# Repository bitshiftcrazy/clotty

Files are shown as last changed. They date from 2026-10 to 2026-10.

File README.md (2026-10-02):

# Clotty

Clotty is a uterus-shaped RP2040 period-tracking companion, sensor board and tiny gaming device.

<p align="center">
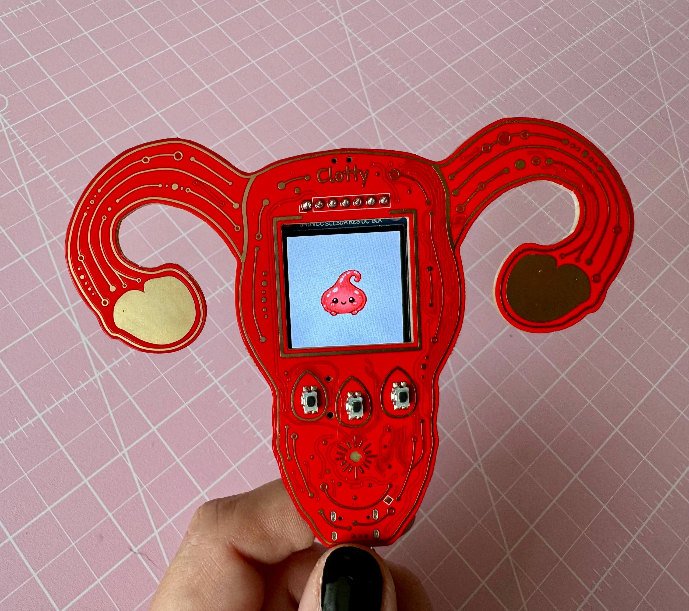
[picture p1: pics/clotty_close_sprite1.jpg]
Clotty showing her little sprite
  
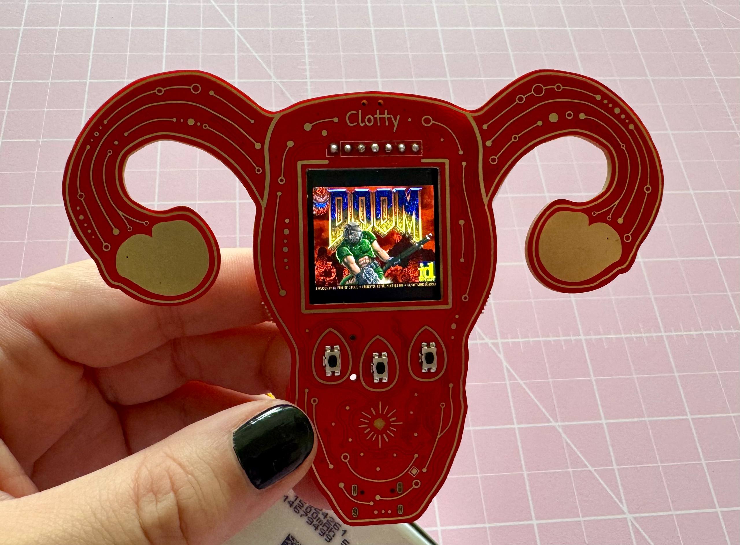
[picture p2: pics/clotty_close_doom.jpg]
Clotty running DOOM
  
</p>

## What is Clotty?

Clotty is a uterus-shaped, custom RP2040-based hybrid between a sensor board and a gaming device.

She originated from the wish to have an offline-only, privacy-focused period tracker that also happens to gamify the unpleasant, recurrent experience of, well, having a period.

Similar to a Tamagotchi, Clotty accompanies the user (currently: me) throughout the cycle. The goal is to keep her (and ideally myself) alive and happy, while her mood, constitution and little quests change according to the current cycle phase. Some of those quests interact with the physical environment through the board's sensors.

Clotty keeps track of cycle lengths and period dates, but she is **not a medical device** beyond that basic tracking functionality.

Naturally, she runs DOOM as well.

## Current Status

> [!WARNING]
> **Work in progress!**
>
> Clotty is currently at the **first working prototype** stage.
>
> Basic board functionality has been tested and confirmed, but there are known hardware issues and plenty of things I still want to improve.
>
> Please keep that in mind before having this revision fabricated.

Current (basic) bring-up status:

- RP2040 boots and can be flashed
- USB enumerates
- display works
- all three physical buttons work
- both capacitive-touch ovaries work
- temperature sensor works
- ambient-light sensor works
- accelerometer works
- Hall sensor works
- RTC works
- RGB LED works
- LiPo charging works
- basic battery-powered operation works
- DOOM runs
- nothing has exploded (yet)

However, testing is still ongoing! 

## Features

Clotty currently or eventually aims to provide:

- completely offline period tracking
- storage of previous cycle lengths and period dates
- basic prediction of likely future period dates
- cycle-phase-dependent moods
- cycle-phase-dependent quests
- cycle-phase-dependent profound wisdom (eg "everyone hates you" during luteal)
- sensor-based interactions with the environment
- small minigames
- animated Clotty sprites
- RGB cycle-phase indication (menacing menstruation maroon, friendly follicular fuchsia, overjoyed ovulation orchid, looming luteal lava...just examples)
- capacitive-touch ovaries for directional interaction
- battery-powered portable operation
- unreasonable amounts of tiny pixel-art accessories
- DOOM, obviously

## Hardware

Main hardware includes:

- **RP2040** microcontroller
- **W25Q128JVSIQ** 128 Mbit / 16 MiB QSPI flash
- **1.3" 240×240 IPS TFT**, driven by an ST7789
- **RV-8263-C7** real-time clock
- RGB LED
- three physical push buttons
- two capacitive-touch ovaries
- USB-C connector
- LiPo charging and power-management circuitry
- currently a 1,500mAh LiPo

<p align="center">
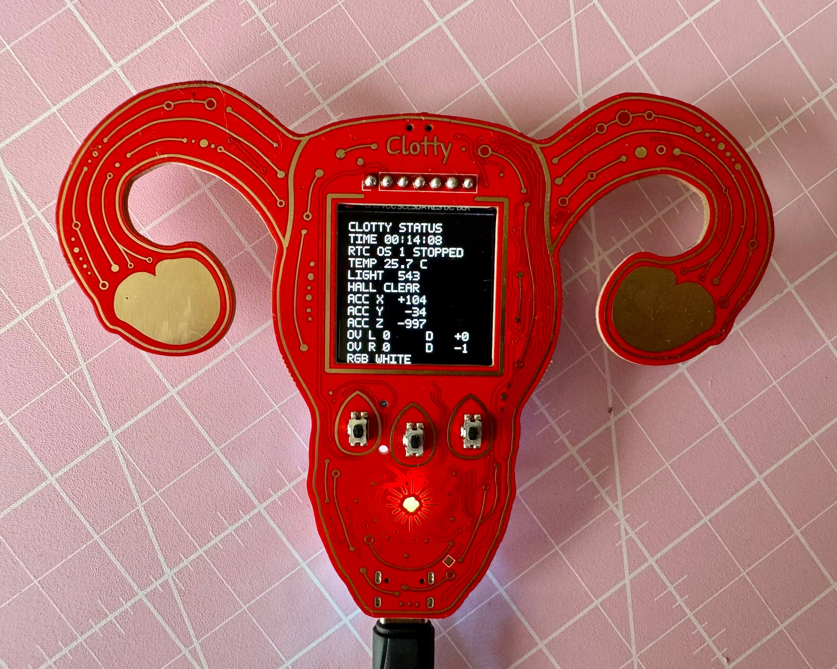
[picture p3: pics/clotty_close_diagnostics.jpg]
Clotty displaying live sensor diagnostics
  
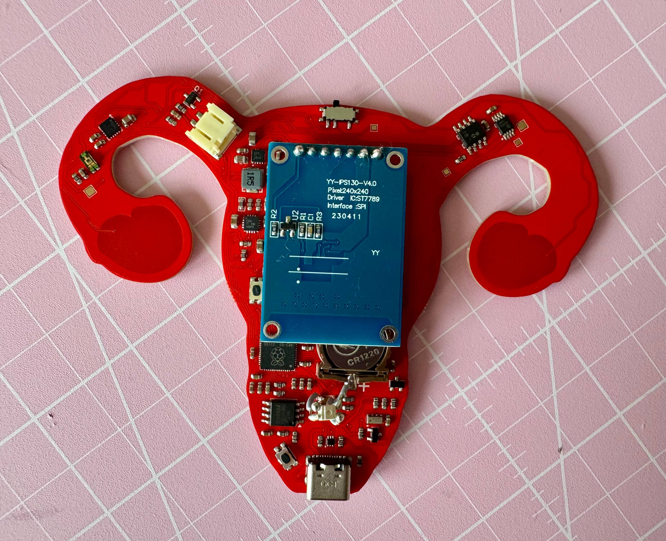
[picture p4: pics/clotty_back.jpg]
Back side of the Clotty PCB
  
</p>

### Sensors

Clotty's sensor selection follows a very scientific design process largely based on "that would be kinda neat".

- **MCP9808-E/MS**: temperature
- **TEMT6000X01**: ambient light
- **LIS3DHTR**: 3-axis accelerometer
- **DRV5032FADBZR**: Hall-effect sensor
- **CAP1203**: capacitive-touch controller for the ovaries

Possible gameplay uses include things like warming Clotty up for a "hot water bottle" quest, putting her somewhere dark for a nap, moving around, or interacting with magnets for no particularly defensible reason.

### Display and Controls

Clotty uses a 240×240 IPS TFT driven by an ST7789.

Controls consist of:

- three physical push buttons
- capacitive-touch ovaries for left and right

The physical buttons are intended mainly for menu navigation and will eventually receive translucent red resin caps shaped like blood drops.

The ovaries are intended for directional or contextual interaction.

Yes, the ovaries also work as controls in DOOM.

### Power

Clotty is designed for portable LiPo-powered operation.

The board includes:

- USB-C input
- LiPo charging
- buck-boost conversion
- power-path / power-selection circuitry
- RTC backup battery

See the schematic for the exact implementation.

## Design

Primarily, the uterus-shape was chosen because it's a period tracking device and subtlety is not exactly my strength.
Periods and reproductive health are still stigmatised too often and Clotty's design is meant to help normalising a biological cycle thanks to which all of us are here in the first place.

But it also turns out that, for reasons nature most likely did not intend, a uterus is surprisingly game-controller-shaped.

The ovaries make convenient touch areas, the centre provides enough room for a display, and the overall shape sits well in the hands.

And yes, the USB-C connector is located at the cervix where it belongs.

<p align="center">
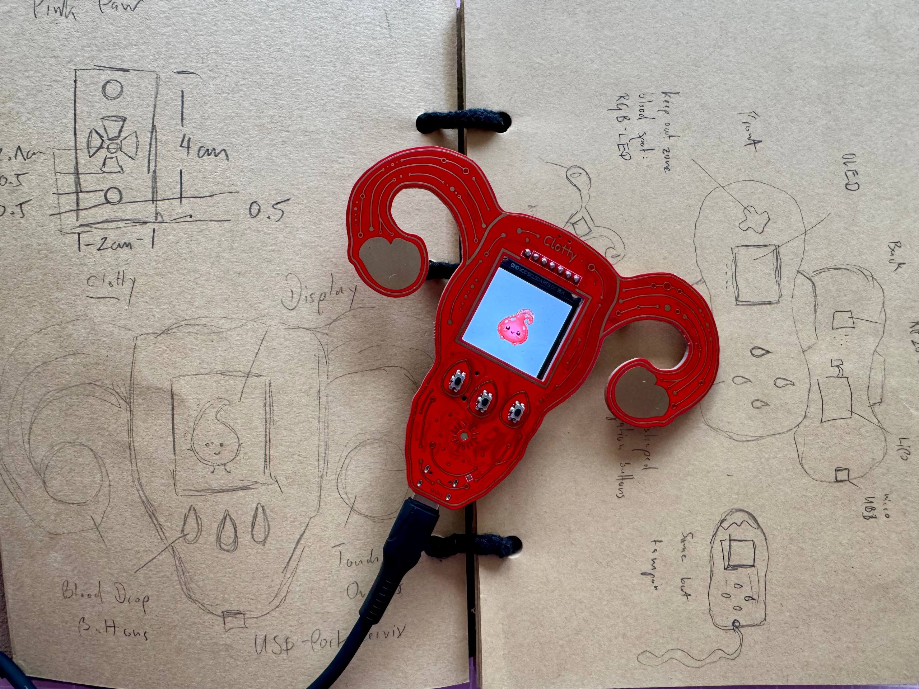
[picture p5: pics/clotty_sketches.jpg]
Early Clotty design sketches together with the finished PCB
  
</p>

Earlier concepts included tampon-shaped and period-pad-shaped devices before the uterus eventually won.

## Known Issues

This revision is a prototype and has known mechanical and layout problems.

Known issues currently include:

- the LiPo JST connector is oriented badly and is difficult to use without brute-forcing the thing in
- the RTC backup battery holder makes the display sit further away from the PCB than intended
- there are currently no proper mounting holes for the planned enclosure (I kinda forgot)
- several component-placement and routing decisions deserve reconsideration (to put it politely)
- mechanical integration with the final case is still unfinished

The board works, but this revision should not be mistaken for a polished production design!

Hardware fixes and cleanup will happen on the `hw-devel` branch before being merged into `main`.

## Fabrication

Fabrication files are available in [`fabrication/`](fabrication/).

The directory contains:

- ready-to-upload Gerber archive
- unpacked Gerbers
- drill files
- JLCPCB BOM
- JLCPCB component-placement file

The current fabrication output corresponds to the prototype revision described above.

Again: **read the Known Issues section before ordering boards.**

## Building / Manufacturing

The project is designed in KiCad.

The repository contains:

- KiCad schematic
- KiCad PCB layout
- project-specific design rules
- local symbol libraries
- local footprint libraries
- artwork used for the PCB
- fabrication output
- schematic PDF

The local libraries are included so the project should not depend on random symbols and footprints disappearing from somewhere on the internet.

If you manufacture this board yourself, verify the BOM, footprints, component availability and fabrication files before ordering. Hardware is unforgiving and I am merely a person on the internet who likes putting USB ports into uteruses.

## Software

Clotty's main application software is still under development and is not yet part of a proper release.
But the firmware will appear in this repo, too.

The planned first usable version includes:

- date and time setup
- entering previous cycle dates / lengths
- entering the current period start date
- simple estimation of the next likely period
- cycle-phase tracking
- animated Clotty states
- small quests
- sensor interactions
- basic menu navigation

The software is deliberately not intended to perform medical analysis!

## DOOM

Clotty can run DOOM.

The DOOM build is based on [`kilograham/rp2040-doom`](https://github.com/kilograham/rp2040-doom).

My Clotty-specific fork lives here:

[`bitshiftcrazy/rp2040-doom`](https://github.com/bitshiftcrazy/rp2040-doom)

For Clotty I replaced the original Pico scanvideo output with a simple blocking SPI backend for the 240×240 ST7789 display and adapted the controls to use the physical buttons and capacitive-touch ovaries.

DOOM renders at 320×200 and is horizontally scaled to 240×200 for the display.

## Repository Structure

```text
.
├── artwork/              PCB artwork and source SVGs
├── docs/                 documentation and schematic PDF
├── fabrication/          Gerbers, BOM and placement files
├── libraries/            project-local KiCad symbols and footprints
├── pics/                 README images
├── clotty.kicad_dru      KiCad design rules
├── clotty.kicad_pcb      PCB layout
├── clotty.kicad_pro      KiCad project
├── clotty.kicad_sch      schematic
├── fp-lib-table
└── sym-lib-table
```

## Documentation

A PDF export of the current schematic can be found here:

[`docs/clotty.pdf`](docs/clotty.pdf)

The full KiCad project is available in the repository root.

More detailed project documentation, design background and development notes will also be published on my blog:

[missmolerat.com](https://missmolerat.com/)

## Roadmap

Roughly:

- fix JST placement
- improve RTC backup-battery placement
- add proper enclosure mounting points
- clean up placement and routing
- design the enclosure
- finish the first actual Clotty application
- add cycle-phase logic
- add quests and sensor interactions
- make far too many sprites
- design resin blood-drop button caps
- continue finding increasingly unnecessary things for a uterus to do

## License

- hardware design files: **CERN Open Hardware Licence Version 2 – Strongly Reciprocal (CERN-OHL-S-2.0)**
- original artwork and documentation: **CC BY-SA 4.0**

DOOM itself and the Clotty DOOM fork are not covered by the hardware licence of this repository.

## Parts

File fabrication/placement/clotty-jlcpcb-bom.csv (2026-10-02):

Comment | Designator | Footprint | JLCPCB Part # optional
10uF | C_ACCEL_BULK1,C_BAT1,C_BQ_OUT1,C_TPS_IN1,C_TPS_OUT1,C_TPS_OUT2 | Capacitor_SMD:C_0805_2012Metric
100nF | C_ACCEL_IO1,C_ACCEL_VDD1,C_ADCAVDD1,C_CAP1203_VDD1,C_DVDD1,C_DVDD2,C_FLASH1,C_HALL1,C_IOVDD1,C_IOVDD2,C_IOVDD3,C_IOVDD4,C_IOVDD5,C_IOVDD6,C_LIGHT1,C_MCP9808,C_RTC_VDD1,C_TPS_IN_HF1,C_TPS_OUT_HF1,C_USBVDD1,C_VBAT_ADC1,C_VINA1 | Capacitor_SMD:C_0603_1608Metric
4.7uF | C_BQ_IN1 | Capacitor_SMD:C_0805_2012Metric
1uF | C_VREGIN1,C_VREGOUT1 | Capacitor_SMD:C_0603_1608Metric
15pF | C_XIN1,C_XOUT1 | Capacitor_SMD:C_0603_1608Metric
 | D1 | clotty:SOT-23-3_L2.9-W1.3-P1.90-LS2.4-BR | C194653
 | D2 | clotty:SOT-666-6_L1.6-W1.2-P0.50-LS1.6-BR | C15999
TPS63031DSKR | IC1 | clotty:SON-10_L2.5-W2.5-P0.50-TL-EP | C15516
Display | J1 | Connector_PinHeader_2.54mm:PinHeader_1x07_P2.54mm_Vertical
USB_C_Receptacle_USB2.0_16P | J2 | Connector_USB:USB_C_Receptacle_GCT_USB4105-xx-A_16P_TopMnt_Horizontal | C3020560
Battery Conn | J_BATT1 | clotty:CONN-SMD_P2.00_S2B-PH-SM4-TB-LF-SN | C295747
1.5uH | L_TPS1 | clotty:IND-SMD_L4.5-W4.1_SRP4020TA
 | Q1 | clotty:SOT-23-3_L2.9-W1.6-P1.90-LS2.8-BR | C332302
100Ohm | R_B1,R_G1 | Resistor_SMD:R_0603_1608Metric
1MOhm | R_BAT_BOTTOM1,R_BAT_TOP1,R_EN_PD1 | Resistor_SMD:R_0603_1608Metric
1kOhm | R_BOOT1,R_XOUT1 | Resistor_SMD:R_0603_1608Metric
5.1kOhm | R_CC1,R_CC2 | Resistor_SMD:R_0603_1608Metric
100kOhm | R_CHG_PULL1,R_PG_PULL1,R_RTC_INT1,R_TOUCH_INT1 | Resistor_SMD:R_0603_1608Metric
10kOm | R_CS_PULL1 | Resistor_SMD:R_0603_1608Metric
1.5kOhm | R_ILIM1 | Resistor_SMD:R_0603_1608Metric
3kOhm | R_ISET1 | Resistor_SMD:R_0603_1608Metric
10kOhm | R_LIGHT1 | Resistor_SMD:R_0603_1608Metric
4.7kOhm | R_PULL_SCL1,R_PULL_SDA1 | Resistor_SMD:R_0603_1608Metric
220Ohm | R_R1 | Resistor_SMD:R_0603_1608Metric
0Ohm | R_SHIELD1 | Resistor_SMD:R_0603_1608Metric
46.4kOhm | R_TMR1 | Resistor_SMD:R_0603_1608Metric
27Ohm | R_USB_DM1,R_USB_DP1 | Resistor_SMD:R_0603_1608Metric
470Ohm | R_VBACKUP1 | Resistor_SMD:R_0603_1608Metric
 | SW1 | clotty:SW-SMD_SSSS811101 | C109335
 | SW_A1,SW_B1,SW_BOOTSEL1,SW_C1,SW_RST1 | clotty:KEY-SMD_KMR2XXGXXX | C72443
NCP18XH103F03RB | TH1 | clotty:R0603 | C13564
RP2040 | U1 | Package_DFN_QFN:QFN-56-1EP_7x7mm_P0.4mm_EP3.2x3.2mm | C2040
W25Q128JVS | U2 | Package_SO:SOIC-8_5.3x5.3mm_P1.27mm | C97521
 | U3 | clotty:VQFN-16_L3.0-W3.0-P0.50-TL-EP1.7 | C2865459
 | U5 | clotty:MSOP-8_L3.0-W3.0-P0.65-LS4.9-BL | C94847
 | U6 | clotty:LGA-16_L3.0-W3.0-P0.50-TL | C15134
 | U7 | clotty:SENSORS-SMD_TEMT6000X01 | C94098
 | U8 | clotty:SOIC-8_L5.0-W4.0-P1.27-LS6.0-BL | C1522284
 | U9 | clotty:SOT-23-3_L2.9-W1.3-P0.95-LS2.4-BR | C140921
 | U10 | clotty:DFN-8_L3.2-W1.5-P0.9-BL | C5137460
12MHz | Y1 | clotty:CRYSTAL-SMD_4P-L3.2-W2.5-BL | C20625731

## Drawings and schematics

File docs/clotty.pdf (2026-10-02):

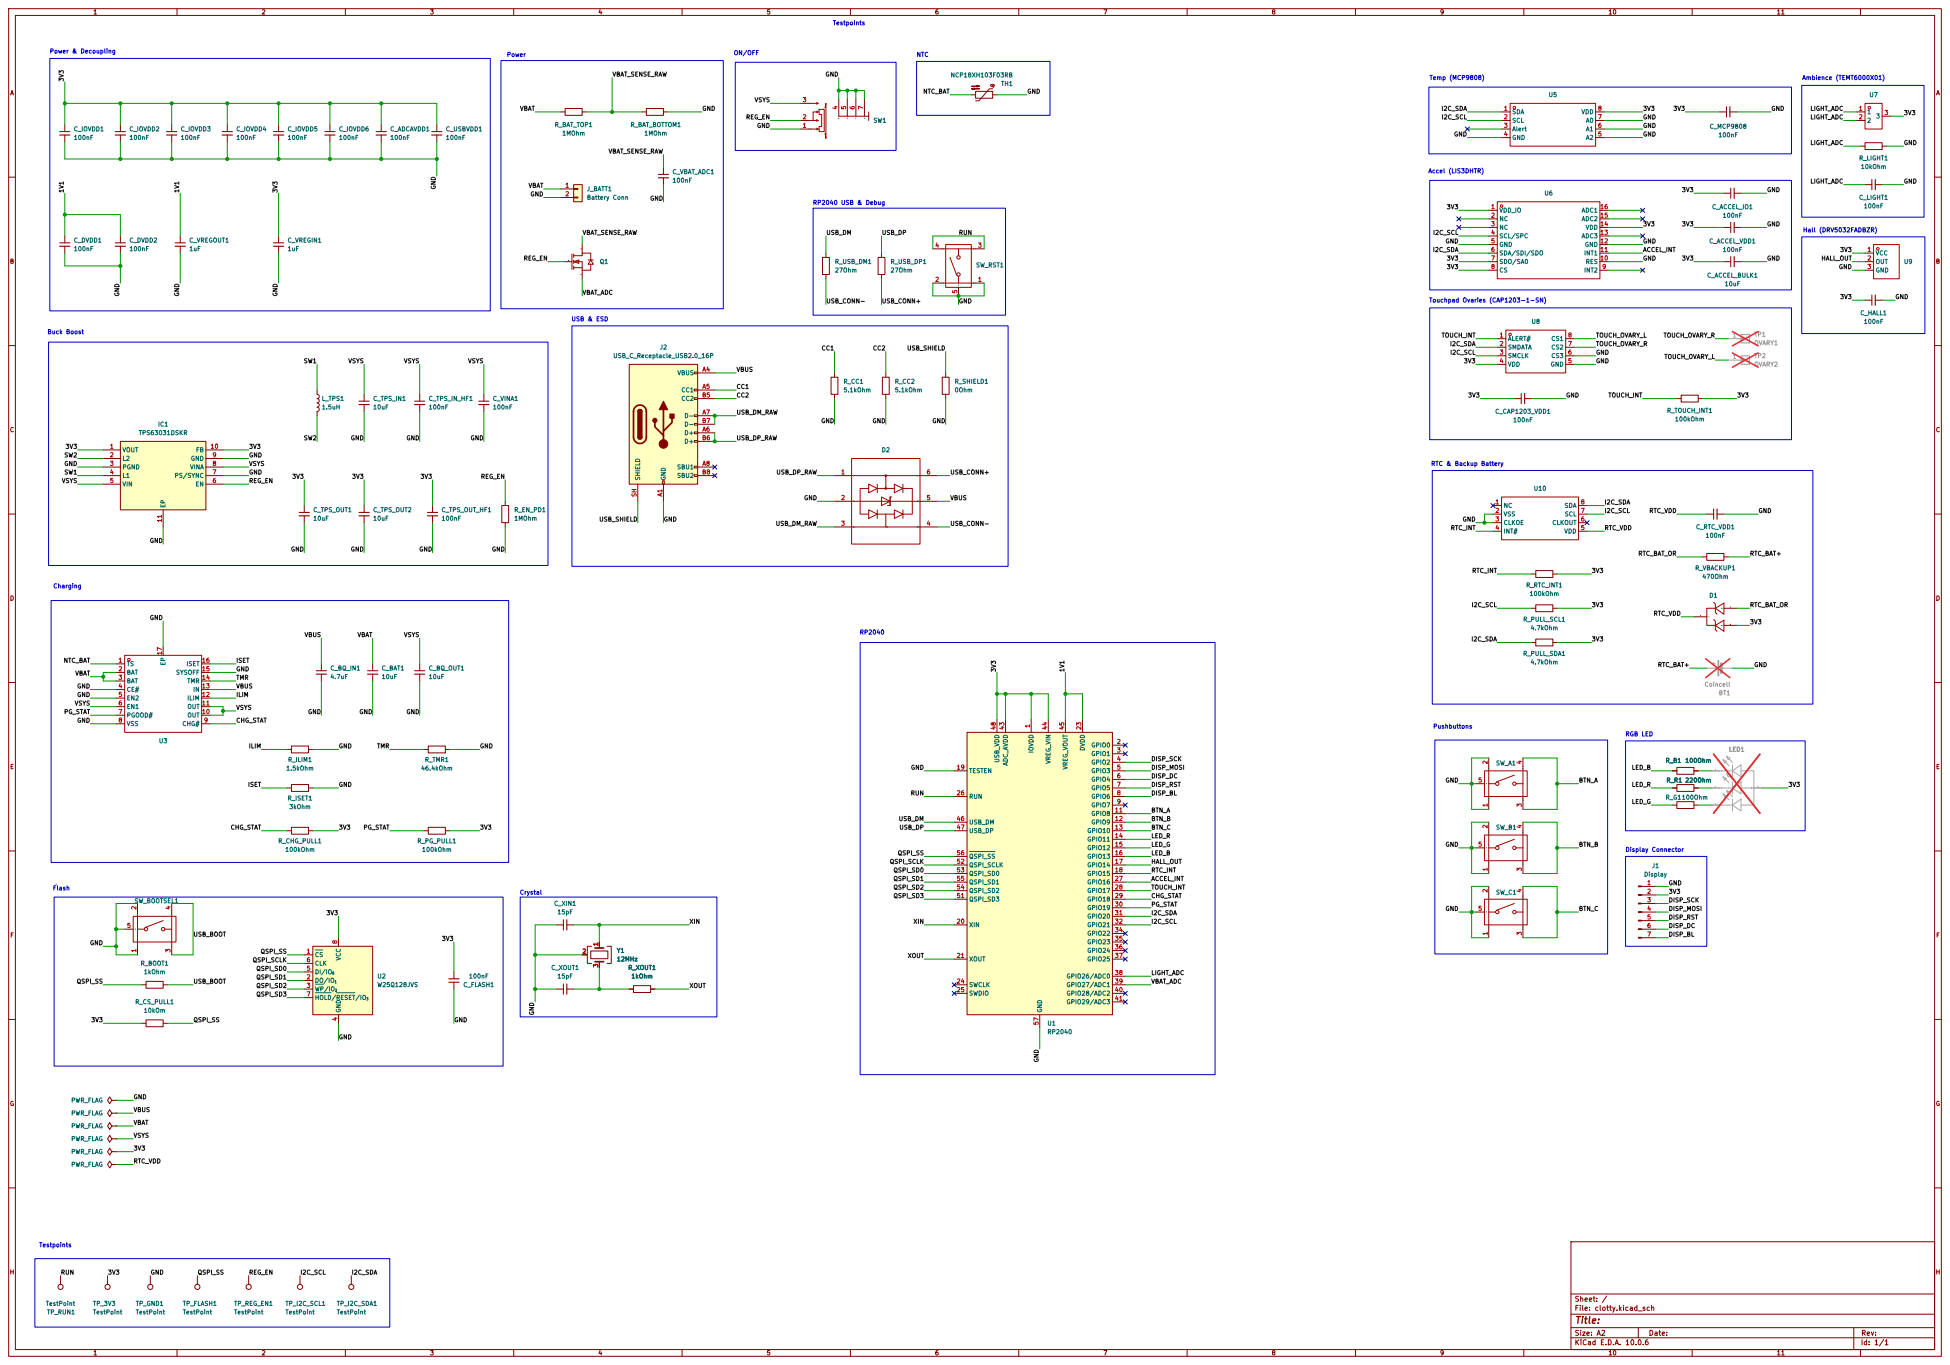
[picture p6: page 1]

4 DI/IO0 5 CLK 6 HOLD/RESET/IO3 7 VCC

Size: A2 | Rev:
KiCad E.D.A. 10.0.6 | Id: 1/1

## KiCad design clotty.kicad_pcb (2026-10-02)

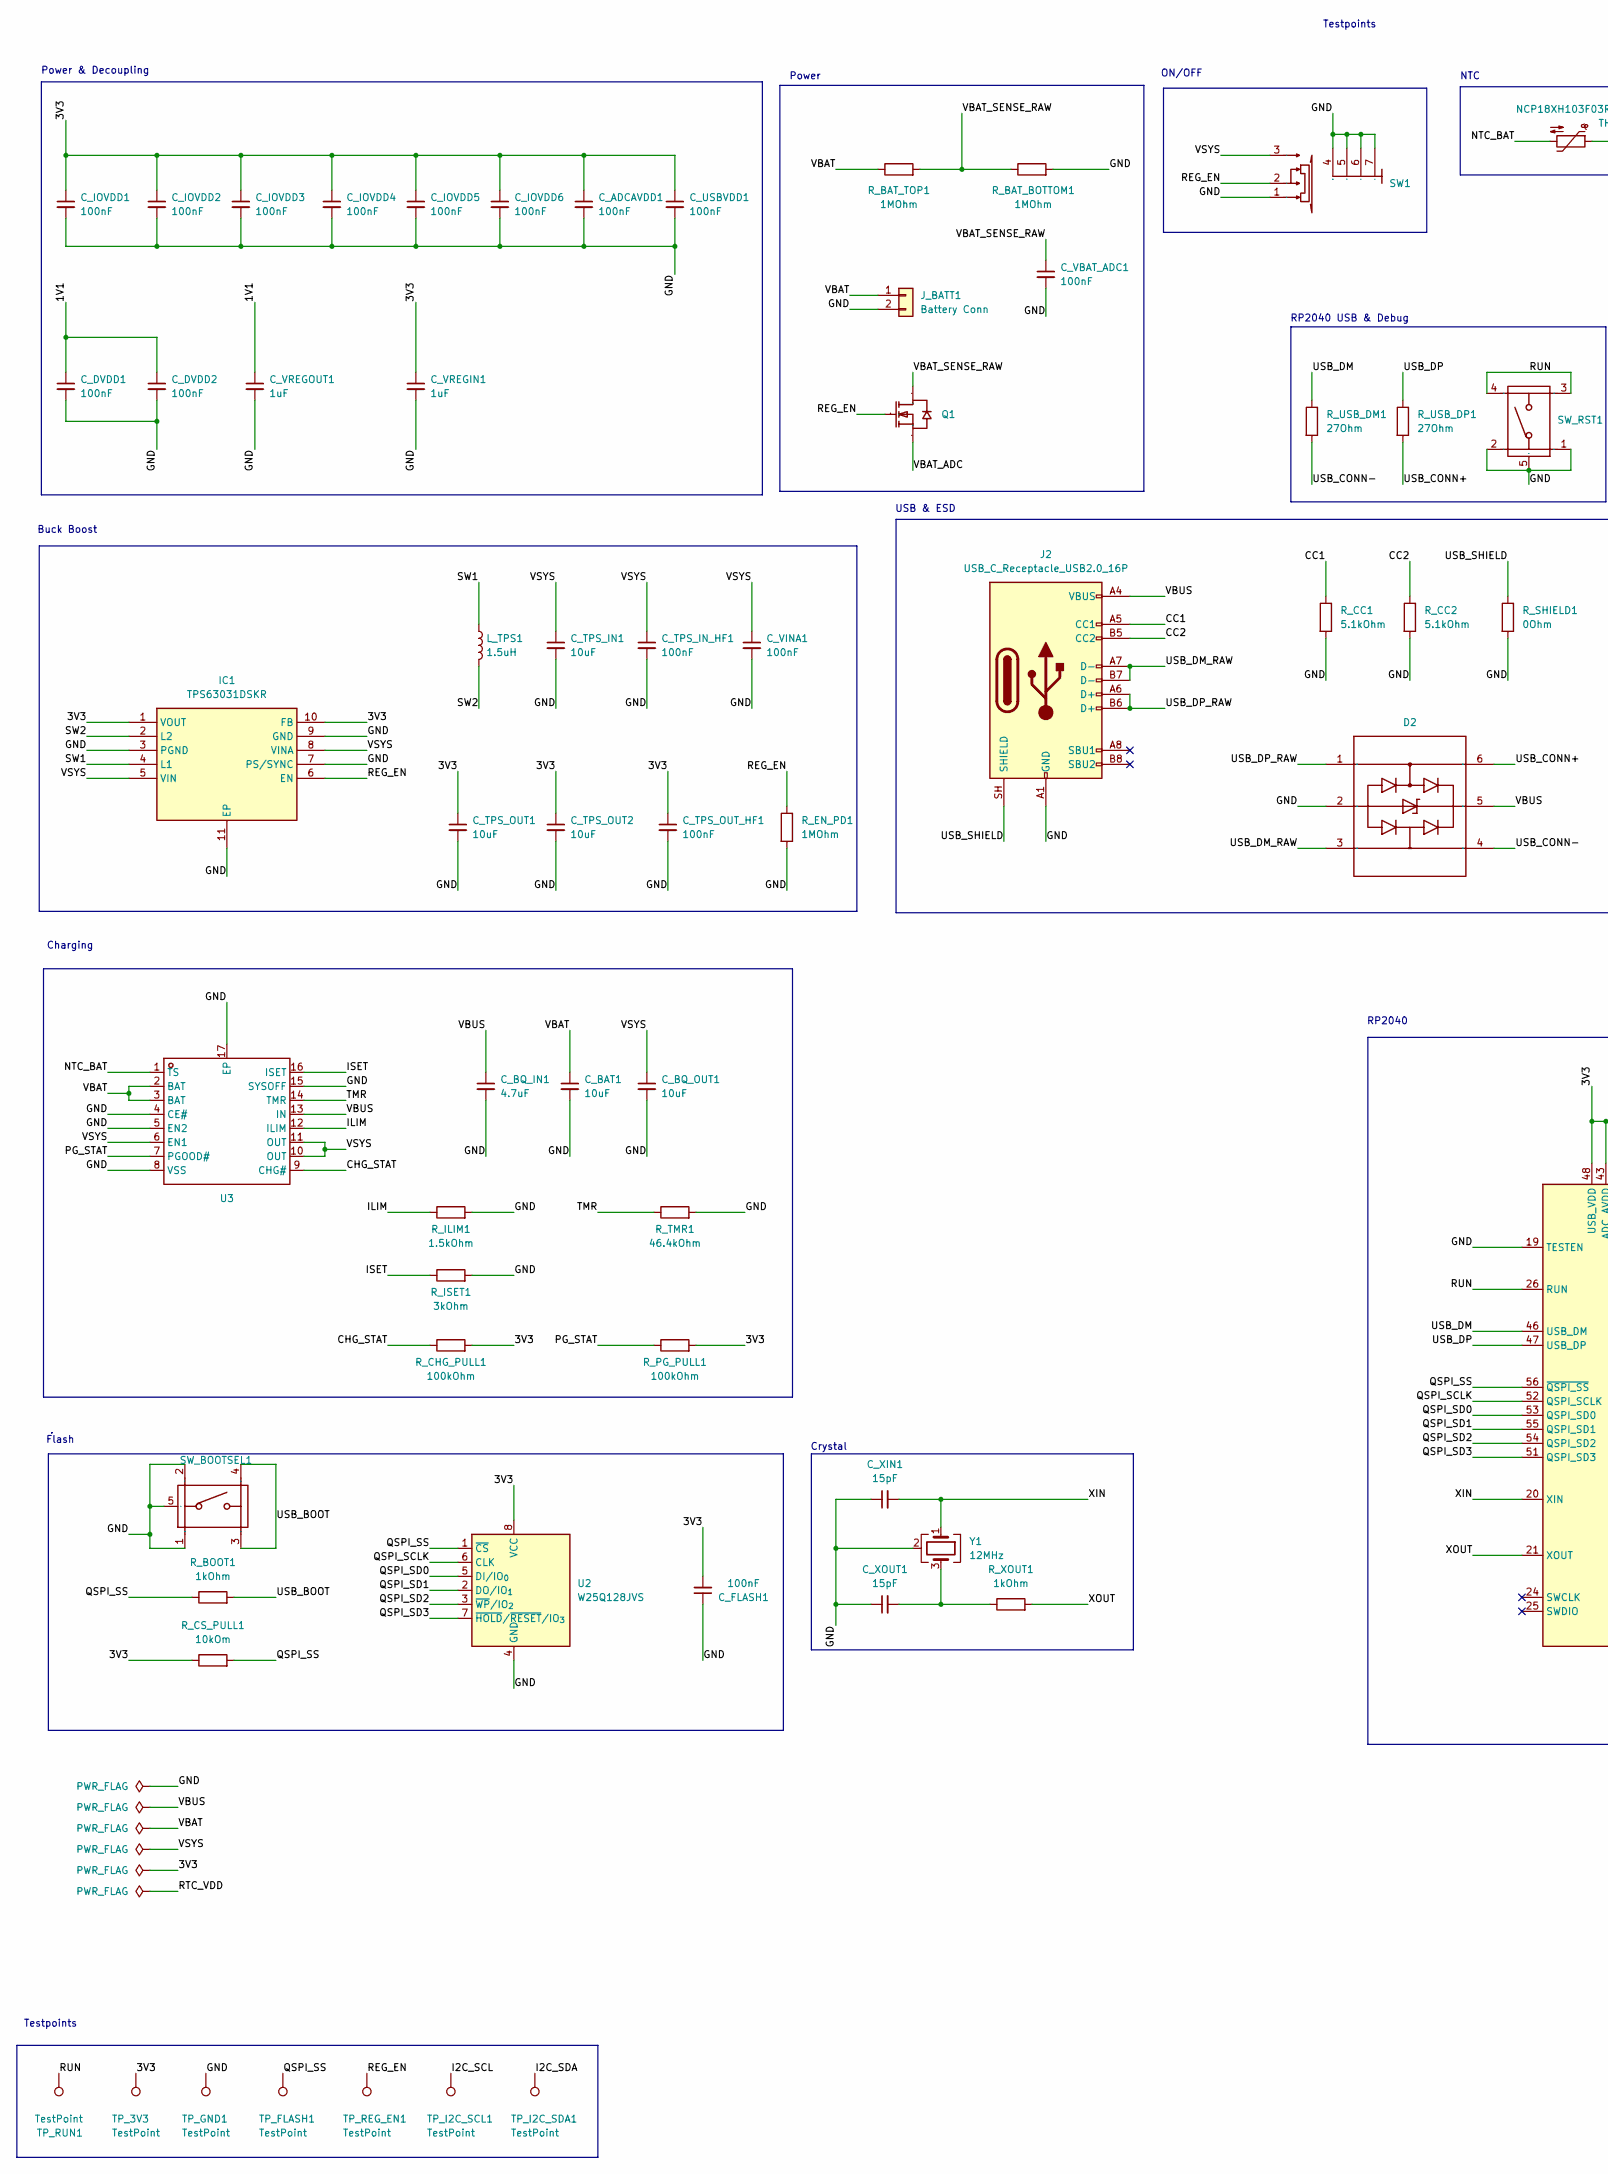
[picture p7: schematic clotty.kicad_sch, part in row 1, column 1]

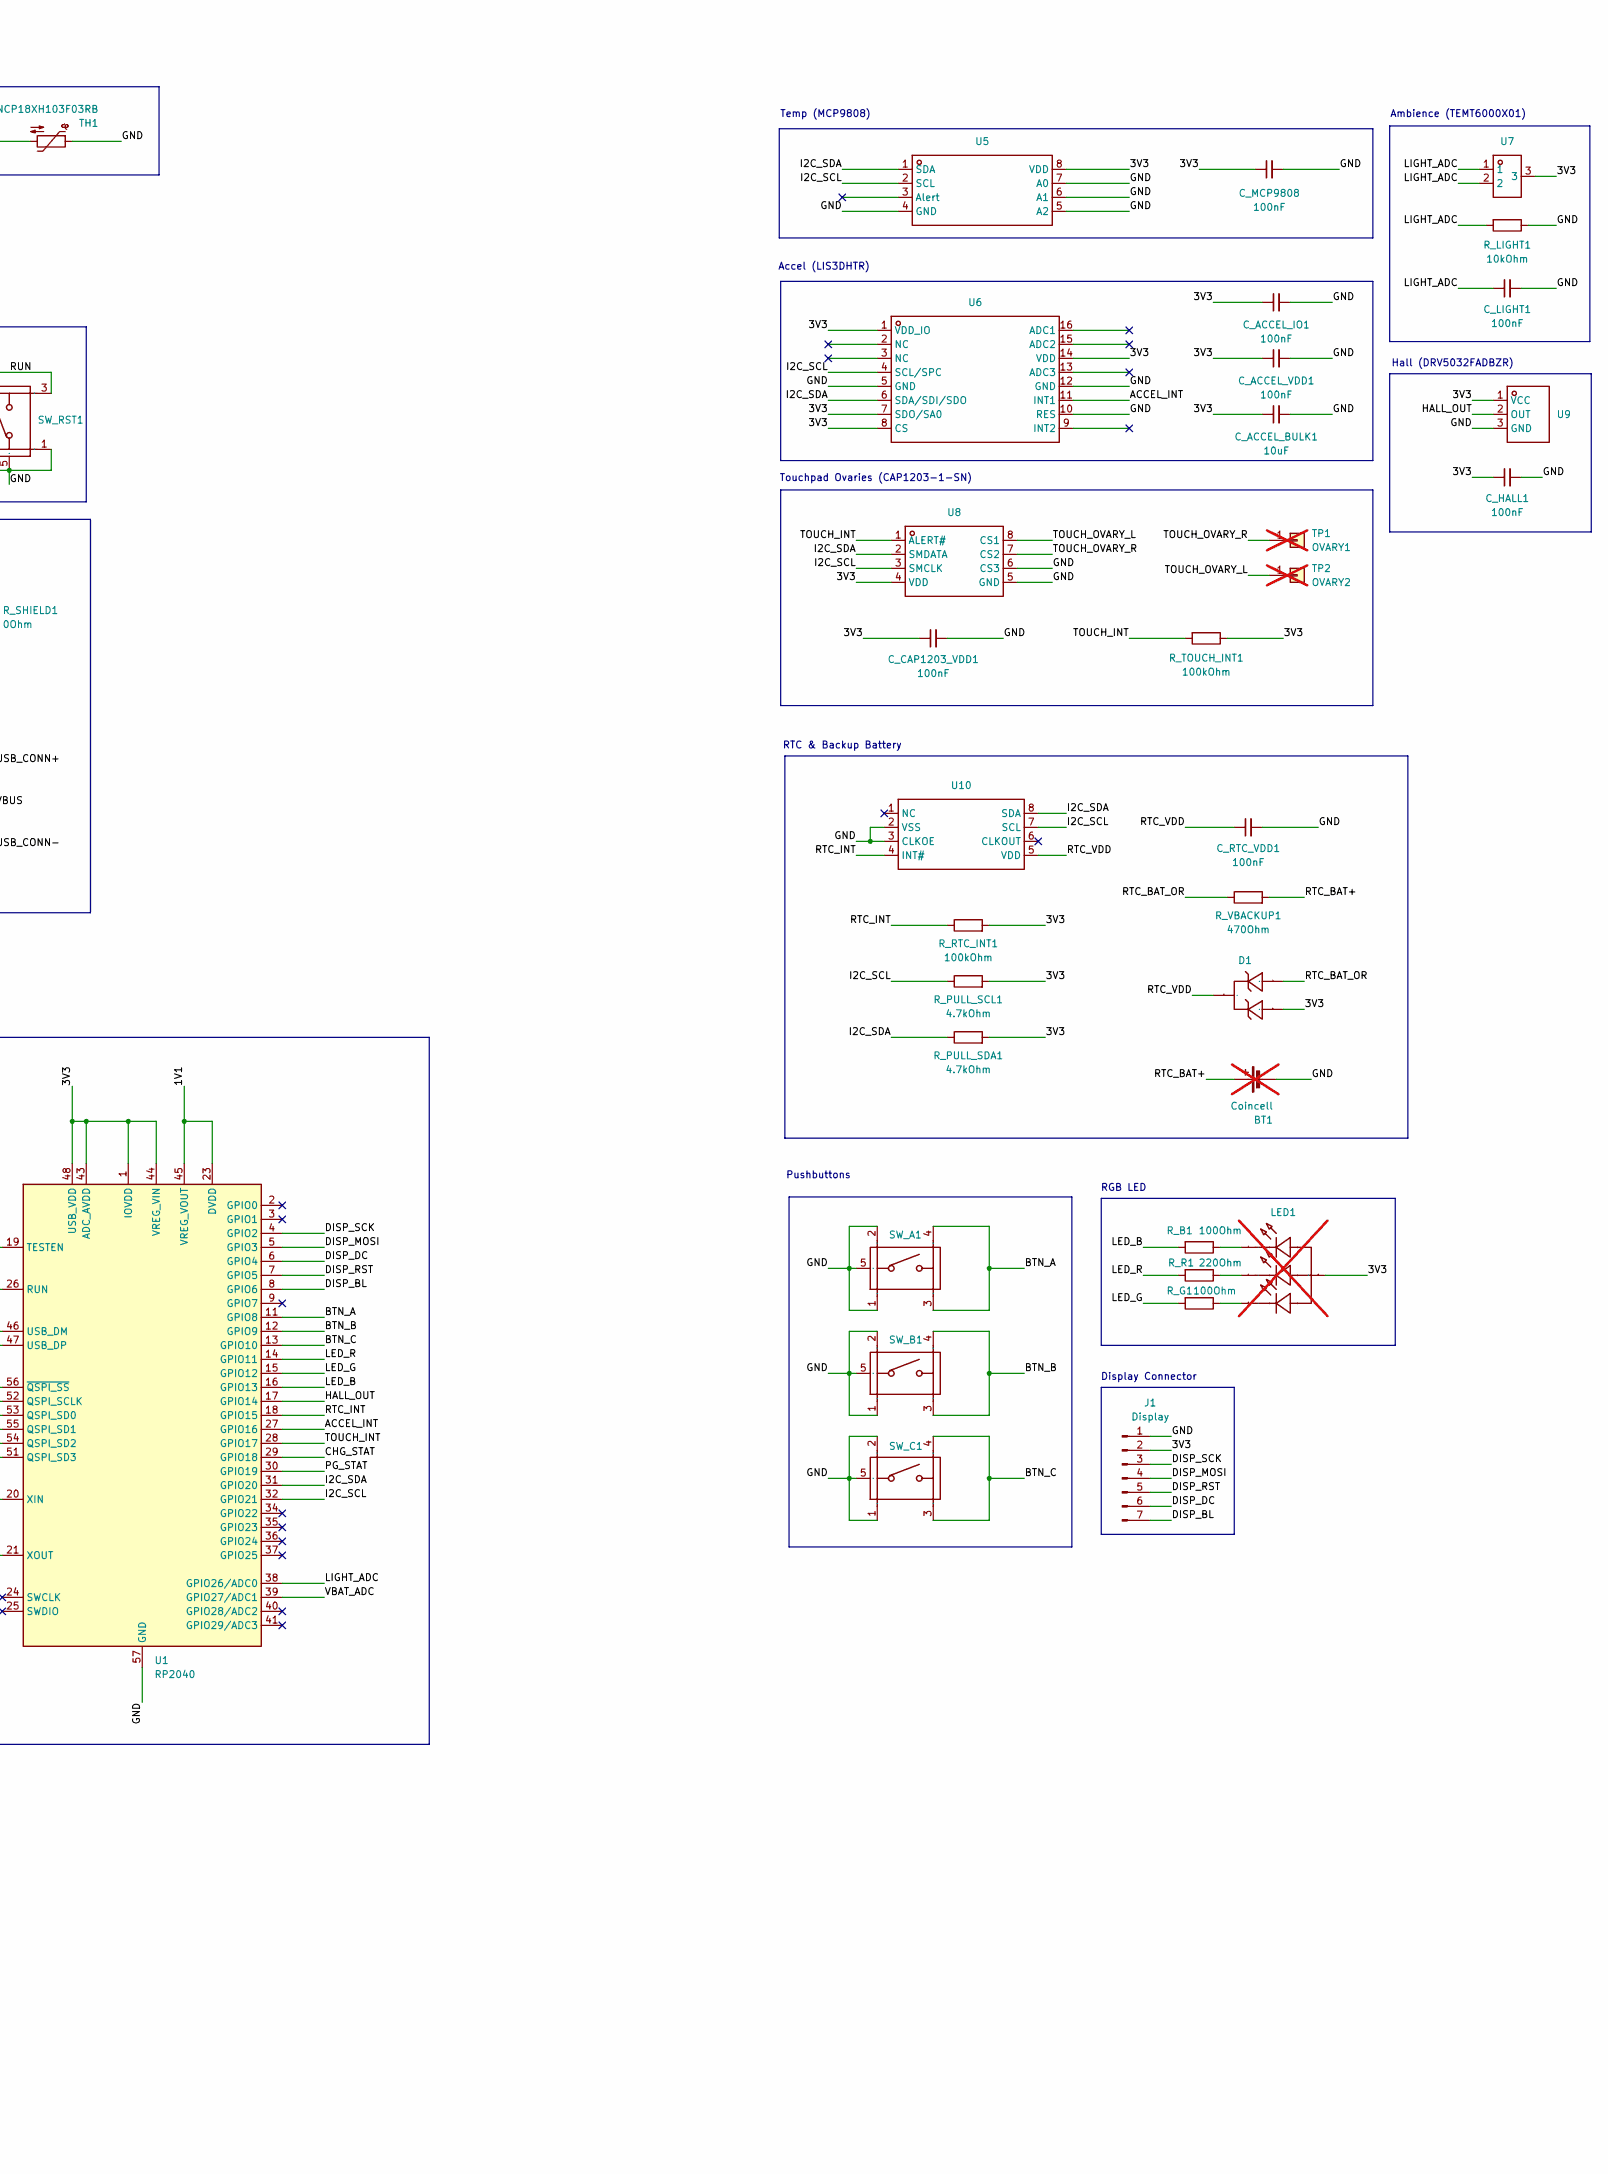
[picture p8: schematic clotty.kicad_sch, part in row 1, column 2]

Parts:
BT1: Coincell; BAT-SMD_KEYSTONE-1056; not fitted
C_ACCEL_BULK1: 10uF; C_0805_2012Metric
C_ACCEL_IO1: 100nF; C_0603_1608Metric
C_ACCEL_VDD1: 100nF; C_0603_1608Metric
C_ADCAVDD1: 100nF; C_0603_1608Metric
C_BAT1: 10uF; C_0805_2012Metric
C_BQ_IN1: 4.7uF; C_0805_2012Metric
C_BQ_OUT1: 10uF; C_0805_2012Metric
C_CAP1203_VDD1: 100nF; C_0603_1608Metric
C_DVDD1, C_DVDD2: 100nF; C_0603_1608Metric
C_FLASH1: 100nF; C_0603_1608Metric
C_HALL1: 100nF; C_0603_1608Metric
C_IOVDD1, C_IOVDD2, C_IOVDD3, C_IOVDD4, C_IOVDD5, C_IOVDD6: 100nF; C_0603_1608Metric
C_LIGHT1: 100nF; C_0603_1608Metric
C_MCP9808: 100nF; C_0603_1608Metric
C_RTC_VDD1: 100nF; C_0603_1608Metric
C_TPS_IN1: 10uF; C_0805_2012Metric
C_TPS_IN_HF1: 100nF; C_0603_1608Metric
C_TPS_OUT1, C_TPS_OUT2: 10uF; C_0805_2012Metric
C_TPS_OUT_HF1: 100nF; C_0603_1608Metric
C_USBVDD1: 100nF; C_0603_1608Metric
C_VBAT_ADC1: 100nF; C_0603_1608Metric
C_VINA1: 100nF; C_0603_1608Metric
C_VREGIN1: 1uF; C_0603_1608Metric
C_VREGOUT1: 1uF; C_0603_1608Metric
C_XIN1: 15pF; C_0603_1608Metric
C_XOUT1: 15pF; C_0603_1608Metric
D1: SOT-23-3_L2.9-W1.3-P1.90-LS2.4-BR; Manufacturer Part BAS70-05,215; LCSC Part Name 电压:70V 电流:70mA
D2: SOT-666-6_L1.6-W1.2-P0.50-LS1.6-BR; Manufacturer Part USBLC6-2P6; LCSC Part Name 单向ESD 5.25V截止 峰值脉冲电流：5A@8/20us
IC1: TPS63031DSKR; SON-10_L2.5-W2.5-P0.50-TL-EP; Mouser Part Number 595-TPS63031DSKR
J1: Display; PinHeader_1x07_P2.54mm_Vertical
J2: USB_C_Receptacle_USB2.0_16P; USB_C_Receptacle_GCT_USB4105-xx-A_16P_TopMnt_Horizontal; LCSC Part # C3020560
J_BATT1: Battery Conn; CONN-SMD_P2.00_S2B-PH-SM4-TB-LF-SN; LCSC Part # C295747
LED1: LED-SMD_4P-L3.2-W2.8-LS3.5-TR_150141M173100; Manufacturer Part 150141M173100; LCSC Part Name SMT全彩顶部发光LED; not fitted
L_TPS1: 1.5uH; IND-SMD_L4.5-W4.1_SRP4020TA
Q1: SOT-23-3_L2.9-W1.6-P1.90-LS2.8-BR; Manufacturer Part DMN2056U-7; LCSC Part Name 1个N沟道 耐压:20V 电流:4A
R_B1: 100Ohm; R_0603_1608Metric
R_BAT_BOTTOM1: 1MOhm; R_0603_1608Metric
R_BAT_TOP1: 1MOhm; R_0603_1608Metric
R_BOOT1: 1kOhm; R_0603_1608Metric
R_CC1, R_CC2: 5.1kOhm; R_0603_1608Metric
R_CHG_PULL1: 100kOhm; R_0603_1608Metric
R_CS_PULL1: 10kOm; R_0603_1608Metric
R_EN_PD1: 1MOhm; R_0603_1608Metric
R_G1: 100Ohm; R_0603_1608Metric
R_ILIM1: 1.5kOhm; R_0603_1608Metric
R_ISET1: 3kOhm; R_0603_1608Metric
R_LIGHT1: 10kOhm; R_0603_1608Metric
R_PG_PULL1: 100kOhm; R_0603_1608Metric
R_PULL_SCL1: 4.7kOhm; R_0603_1608Metric
R_PULL_SDA1: 4.7kOhm; R_0603_1608Metric
R_R1: 220Ohm; R_0603_1608Metric
R_RTC_INT1: 100kOhm; R_0603_1608Metric
R_SHIELD1: 0Ohm; R_0603_1608Metric
R_TMR1: 46.4kOhm; R_0603_1608Metric
R_TOUCH_INT1: 100kOhm; R_0603_1608Metric
R_USB_DM1: 27Ohm; R_0603_1608Metric
R_USB_DP1: 27Ohm; R_0603_1608Metric
R_VBACKUP1: 470Ohm; R_0603_1608Metric
R_XOUT1: 1kOhm; R_0603_1608Metric
SW1: SW-SMD_SSSS811101; Manufacturer Part SSSS811101; LCSC Part Name 1.4mm厚、1.5/2.0mm行程的表面贴装型开关
SW_A1: KEY-SMD_KMR2XXGXXX; Manufacturer Part KMR221GLFS; LCSC Part Name 4.6*2.8*1.9mm 立贴 轻触开关
SW_B1: KEY-SMD_KMR2XXGXXX; Manufacturer Part KMR221GLFS; LCSC Part Name 4.6*2.8*1.9mm 立贴 轻触开关
SW_BOOTSEL1: KEY-SMD_KMR2XXGXXX; Manufacturer Part KMR221GLFS; LCSC Part Name 4.6*2.8*1.9mm 立贴 轻触开关
SW_C1: KEY-SMD_KMR2XXGXXX; Manufacturer Part KMR221GLFS; LCSC Part Name 4.6*2.8*1.9mm 立贴 轻触开关
SW_RST1: KEY-SMD_KMR2XXGXXX; Manufacturer Part KMR221GLFS; LCSC Part Name 4.6*2.8*1.9mm 立贴 轻触开关
TH1: NCP18XH103F03RB; R0603; LCSC Part # C13564
TP1: OVARY1; ovary_left; not fitted
TP2: OVARY2; ovary_right; not fitted
TP_3V3: TestPoint; TestPoint_Pad_1.5x1.5mm
TP_FLASH1: TestPoint; TestPoint_Pad_1.0x1.0mm
TP_GND1: TestPoint; TestPoint_Pad_1.5x1.5mm
TP_I2C_SCL1, TP_I2C_SDA1: TestPoint; TestPoint_Pad_1.0x1.0mm
TP_REG_EN1: TestPoint; TestPoint_Pad_1.0x1.0mm
TP_RUN1: TestPoint; TestPoint_Pad_1.0x1.0mm
U1: RP2040; QFN-56-1EP_7x7mm_P0.4mm_EP3.2x3.2mm; LCSC Part # C2040
U2: W25Q128JVS; SOIC-8_5.3x5.3mm_P1.27mm; LCSC Part # C97521
U3: VQFN-16_L3.0-W3.0-P0.50-TL-EP1.7; Manufacturer Part BQ24075RGTT; LCSC Part Name 具有电源路径的独立型单芯线性电池充电器
U5: MSOP-8_L3.0-W3.0-P0.65-LS4.9-BL; Manufacturer Part MCP9808-E/MS; LCSC Part Name ±0.5°C最高精度数字温度传感器
U6: LGA-16_L3.0-W3.0-P0.50-TL; Manufacturer Part LIS3DHTR; LCSC Part Name MEMS数字输出运动传感器：超低功耗、高性能三轴加速度计
U7: SENSORS-SMD_TEMT6000X01; Manufacturer Part TEMT6000X01; LCSC Part Name TEMT6000X01
U8: SOIC-8_L5.0-W4.0-P1.27-LS6.0-BL; Manufacturer Part CAP1203-1-SN; LCSC Part Name CAP1203 1 SN
U9: SOT-23-3_L2.9-W1.3-P0.95-LS2.4-BR; Manufacturer Part DRV5032FADBZR; LCSC Part Name 数字锁存霍尔效应传感器
U10: DFN-8_L3.2-W1.5-P0.9-BL; Manufacturer Part RV-8263-C7-32.768KHZ-20PPM-TA-QA; LCSC Part Name 带 I2C 总线的实时时钟模块
Y1: 12MHz; CRYSTAL-SMD_4P-L3.2-W2.5-BL; LCSC Part # C20625731

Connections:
/1V1: C_DVDD1.1, C_DVDD2.1, C_VREGOUT1.1, U1.23 (DVDD), U1.45 (VREG_VOUT), U1.50 (DVDD)
/3V3: C_ACCEL_BULK1.1, C_ACCEL_IO1.1, C_ACCEL_VDD1.1, C_ADCAVDD1.1, C_CAP1203_VDD1.1, C_FLASH1.2, C_HALL1.1, C_IOVDD1.1, C_IOVDD2.1, C_IOVDD3.1, C_IOVDD4.1, C_IOVDD5.1, C_IOVDD6.1, C_MCP9808.1, C_TPS_OUT1.1, C_TPS_OUT2.1, C_TPS_OUT_HF1.1, C_USBVDD1.1, C_VREGIN1.1, D1.1 (A), IC1.1 (VOUT), IC1.10 (FB), J1.2, LED1.1 (+), R_CHG_PULL1.2, R_CS_PULL1.1, R_PG_PULL1.2, R_PULL_SCL1.2, R_PULL_SDA1.2, R_RTC_INT1.2, R_TOUCH_INT1.1, TP_3V3.1 (1_1), U1.1 (IOVDD), U1.10 (IOVDD), U1.22 (IOVDD), U1.33 (IOVDD), U1.42 (IOVDD), U1.43 (ADC_AVDD), U1.44 (VREG_VIN), U1.48 (USB_VDD), U1.49 (IOVDD), U2.8 (VCC), U5.8 (VDD), U6.1 (VDD_IO), U6.7 (SDO/SA0), U6.8 (CS), U6.14 (VDD), U7.3, U8.4 (VDD), U9.1 (VCC)
/ACCEL_INT: U1.27 (GPIO16), U6.11 (INT1)
/BTN_A: SW_A1.3, SW_A1.4, U1.11 (GPIO8)
/BTN_B: SW_B1.3, SW_B1.4, U1.12 (GPIO9)
/BTN_C: SW_C1.3, SW_C1.4, U1.13 (GPIO10)
/CC1: J2.A5 (CC1), R_CC1.1
/CC2: J2.B5 (CC2), R_CC2.1
/CHG_STAT: R_CHG_PULL1.1, U1.29 (GPIO18), U3.9 (CHG#)
/DISP_BL: J1.7, U1.8 (GPIO6)
/DISP_DC: J1.6, U1.6 (GPIO4)
/DISP_MOSI: J1.4, U1.5 (GPIO3)
/DISP_RST: J1.5, U1.7 (GPIO5)
/DISP_SCK: J1.3, U1.4 (GPIO2)
/GND: BT1.2 (-), C_ACCEL_BULK1.2, C_ACCEL_IO1.2, C_ACCEL_VDD1.2, C_ADCAVDD1.2, C_BAT1.2, C_BQ_IN1.2, C_BQ_OUT1.2, C_CAP1203_VDD1.2, C_DVDD1.2, C_DVDD2.2, C_FLASH1.1, C_HALL1.2, C_IOVDD1.2, C_IOVDD2.2, C_IOVDD3.2, C_IOVDD4.2, C_IOVDD5.2, C_IOVDD6.2, C_LIGHT1.2, C_MCP9808.2, C_RTC_VDD1.2, C_TPS_IN1.2, C_TPS_IN_HF1.2, C_TPS_OUT1.2, C_TPS_OUT2.2, C_TPS_OUT_HF1.2, C_USBVDD1.2, C_VBAT_ADC1.2, C_VINA1.2, C_VREGIN1.2, C_VREGOUT1.2, C_XIN1.1, C_XOUT1.1, D2.2 (GND), IC1.3 (PGND), IC1.7 (PS/SYNC), IC1.9 (GND), IC1.11 (EP), J1.1, J2.A1 (GND), J2.A12 (GND), J2.B1 (GND), J2.B12 (GND), J_BATT1.2, R_BAT_BOTTOM1.2, R_CC1.2, R_CC2.2, R_EN_PD1.2, R_ILIM1.2, R_ISET1.2, R_LIGHT1.1, R_SHIELD1.2, R_TMR1.2, SW1.1, SW1.4, SW1.5, SW1.6, SW1.7, SW_A1.1, SW_A1.2, SW_A1.5, SW_B1.1, SW_B1.2, SW_B1.5, SW_BOOTSEL1.1, SW_BOOTSEL1.2, SW_BOOTSEL1.5, SW_C1.1, SW_C1.2, SW_C1.5, SW_RST1.1, SW_RST1.2, SW_RST1.5, TH1.1, TP_GND1.1 (1_1), U1.19 (TESTEN), U1.57 (GND), U2.4 (GND), U3.4 (CE#), U3.5 (EN2), U3.8 (VSS), U3.15 (SYSOFF), U3.17 (EP), U5.4 (GND), U5.5 (A2), U5.6 (A1), U5.7 (A0), U6.5 (GND), U6.10 (RES), U6.12 (GND), U8.5 (GND), U8.6 (CS3), U9.3 (GND), U10.2 (VSS), U10.3 (CLKOE), Y1.2 (G), Y1.4 (G)
/HALL_OUT: U1.17 (GPIO14), U9.2 (OUT)
/I2C_SCL: R_PULL_SCL1.1, TP_I2C_SCL1.1 (1_1), U1.32 (GPIO21), U5.2 (SCL), U6.4 (SCL/SPC), U8.3 (SMCLK), U10.7 (SCL)
/I2C_SDA: R_PULL_SDA1.1, TP_I2C_SDA1.1 (1_1), U1.31 (GPIO20), U5.1 (SDA), U6.6 (SDA/SDI/SDO), U8.2 (SMDATA), U10.8 (SDA)
/ILIM: R_ILIM1.1, U3.12 (ILIM)
/ISET: R_ISET1.1, U3.16 (ISET)
/LED_B: R_B1.2, U1.16 (GPIO13)
/LED_G: R_G1.2, U1.15 (GPIO12)
/LED_R: R_R1.2, U1.14 (GPIO11)
/LIGHT_ADC: C_LIGHT1.1, R_LIGHT1.2, U1.38 (GPIO26/ADC0), U7.1, U7.2
/NTC_BAT: TH1.2, U3.1 (TS)
/PG_STAT: R_PG_PULL1.1, U1.30 (GPIO19), U3.7 (PGOOD#)
/QSPI_SCLK: U1.52 (QSPI_SCLK), U2.6 (CLK)
/QSPI_SD0: U1.53 (QSPI_SD0), U2.5 (DI/IO_{0})
/QSPI_SD1: U1.55 (QSPI_SD1), U2.2 (DO/IO_{1})
/QSPI_SD2: U1.54 (QSPI_SD2), U2.3 (~WP/IO_{2})
/QSPI_SD3: U1.51 (QSPI_SD3), U2.7 (~HOLD/~RESET/IO_{3})
/QSPI_SS: R_BOOT1.1, R_CS_PULL1.2, TP_FLASH1.1 (1_1), U1.56 (~QSPI_SS), U2.1 (~CS)
/REG_EN: IC1.6 (EN), Q1.1 (G), R_EN_PD1.1, SW1.2, TP_REG_EN1.1 (1_1)
/RTC_BAT+: BT1.1 (+), R_VBACKUP1.2
/RTC_BAT_OR: D1.2 (A), R_VBACKUP1.1
/RTC_INT: R_RTC_INT1.1, U1.18 (GPIO15), U10.4 (INT#)
/RTC_VDD: C_RTC_VDD1.1, D1.3 (C), U10.5 (VDD)
/RUN: SW_RST1.3, SW_RST1.4, TP_RUN1.1 (1_1), U1.26 (RUN)
/SW1: IC1.4 (L1), L_TPS1.1
/SW2: IC1.2 (L2), L_TPS1.2
/TMR: R_TMR1.1, U3.14 (TMR)
/TOUCH_INT: R_TOUCH_INT1.2, U1.28 (GPIO17), U8.1 (ALERT#)
/TOUCH_OVARY_L: TP2.1 (Pin_1_1), U8.8 (CS1)
/TOUCH_OVARY_R: TP1.1 (Pin_1_1), U8.7 (CS2)
/USB_BOOT: R_BOOT1.2, SW_BOOTSEL1.3, SW_BOOTSEL1.4
/USB_CONN+: D2.6 (I/O1), R_USB_DP1.2
/USB_CONN-: D2.4 (I/O2), R_USB_DM1.2
/USB_DM: R_USB_DM1.1, U1.46 (USB_DM)
/USB_DM_RAW: D2.3 (I/O2), J2.A7 (D-), J2.B7 (D-)
/USB_DP: R_USB_DP1.1, U1.47 (USB_DP)
/USB_DP_RAW: D2.1 (I/O1), J2.A6 (D+), J2.B6 (D+)
/USB_SHIELD: J2.SH (SHIELD), R_SHIELD1.1
/VBAT: C_BAT1.1, J_BATT1.1, R_BAT_TOP1.1, U3.2 (BAT), U3.3 (BAT)
/VBAT_ADC: Q1.2 (S), U1.39 (GPIO27/ADC1)
/VBAT_SENSE_RAW: C_VBAT_ADC1.1, Q1.3 (D), R_BAT_BOTTOM1.1, R_BAT_TOP1.2
/VBUS: C_BQ_IN1.1, D2.5 (VBUS), J2.A4 (VBUS), J2.A9 (VBUS), J2.B4 (VBUS), J2.B9 (VBUS), U3.13 (IN)
/VSYS: C_BQ_OUT1.1, C_TPS_IN1.1, C_TPS_IN_HF1.1, C_VINA1.1, IC1.5 (VIN), IC1.8 (VINA), SW1.3, U3.6 (EN1), U3.10 (OUT), U3.11 (OUT)
/XIN: C_XIN1.2, U1.20 (XIN), Y1.1
/XOUT: R_XOUT1.2, U1.21 (XOUT)
unnamed: C_XOUT1.2, R_XOUT1.1, Y1.3
unnamed: LED1.2 (-), R_B1.1
unnamed: LED1.3 (-), R_R1.1
unnamed: LED1.4 (-), R_G1.1

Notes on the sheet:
Crystal
Testpoints
Flash
USB & ESD
Charging
Buck Boost
RP2040
Display Connector
Touchpad Ovaries (CAP1203-1-SN)
Temp (MCP9808)
Hall (DRV5032FADBZR)
ON/OFF
NTC
Power
Pushbuttons
RGB LED
Accel (LIS3DHTR)
Power & Decoupling
Ambience (TEMT6000X01)
RP2040 USB & Debug
RTC & Backup Battery

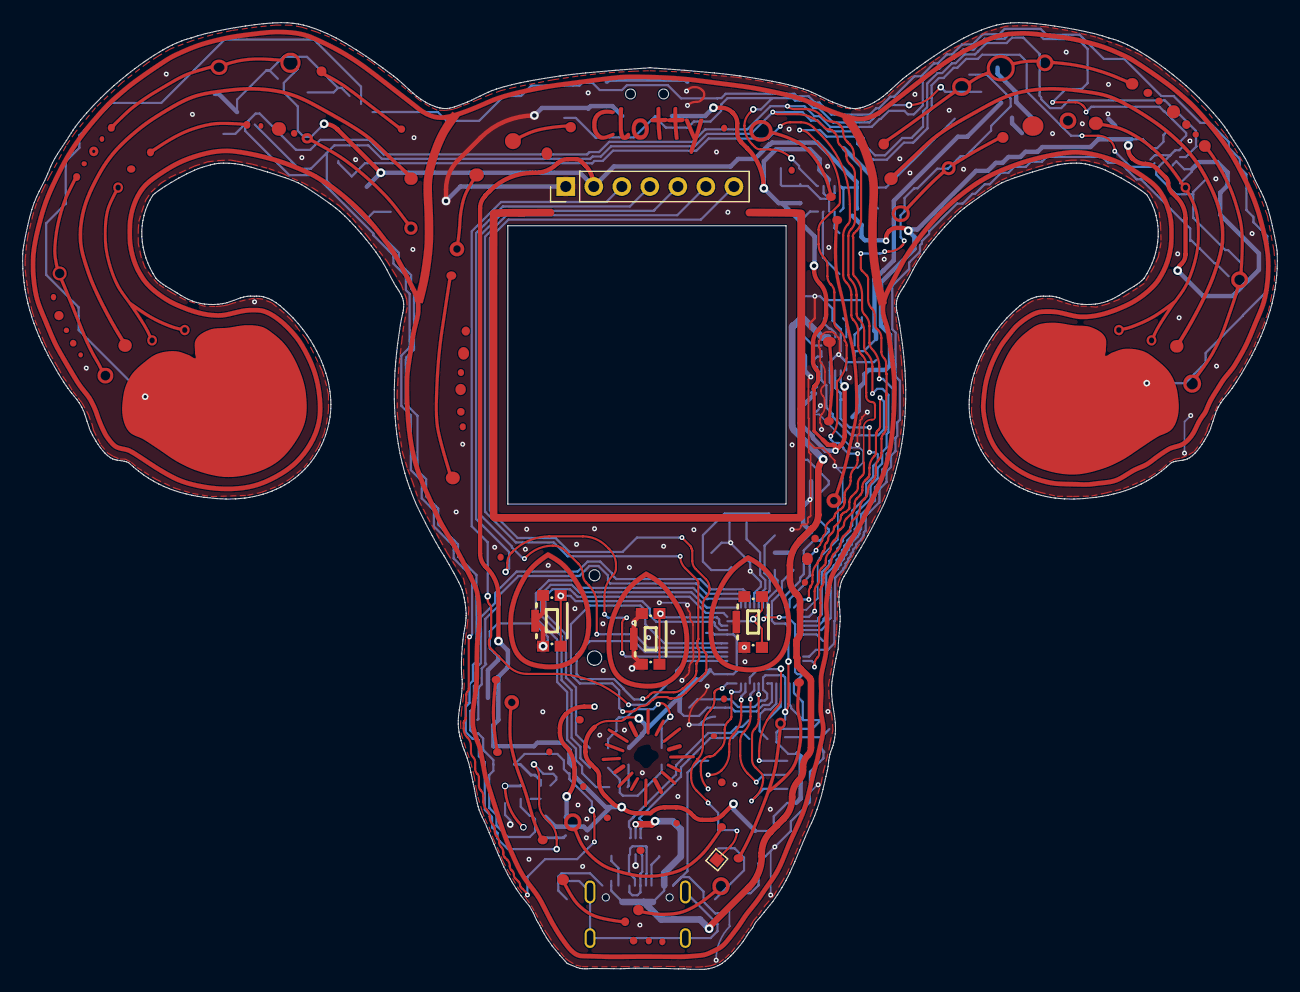
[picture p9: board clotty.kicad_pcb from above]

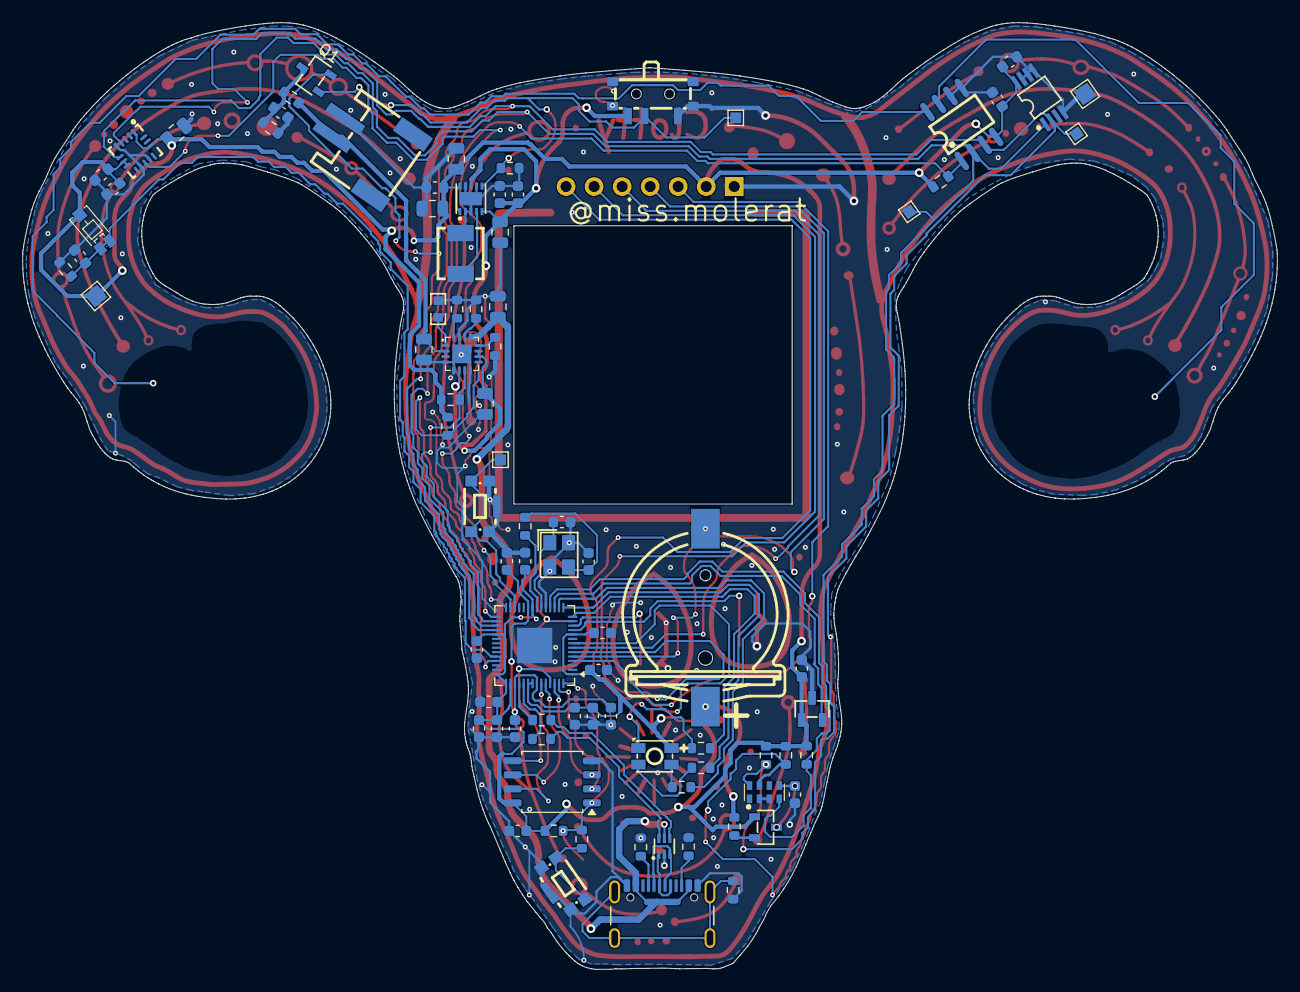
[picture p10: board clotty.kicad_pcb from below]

Board: 2 copper layers, 113.7 x 85.8 mm, 94 parts (87 on the bottom side), 63 nets.

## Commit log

2026-09-30 Ignore local notes and KiCad backups
2026-10-02 HW: Add Clotty prototype hardware design and documentation
    [clotty-B_Cu.gbl, clotty-B_Mask.gbs, clotty-B_Paste.gbp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]
